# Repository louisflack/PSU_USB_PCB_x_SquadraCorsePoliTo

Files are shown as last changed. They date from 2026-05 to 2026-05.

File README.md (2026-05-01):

# PSU_USB Power Board
**Squadra Corse PoliTo — Formula Student (Season SC25)**





## 🏎️ System Overview

This repository contains the hardware design for the PSU_USB board. The primary purpose of this board is to provide a highly stable 5V power supply to electronics boards across the vehicle system. 

Utilizing a standard USB-C connector, the board is designed for maximum utility and ease of use, allowing critical racing electronics to be powered up directly from any standard power supply or PC during bench testing and debugging. 

## ✨ Key Features & Hardware Specifications

* **Connector:** USB-C Female Connector (Molex / Wurth Elektronik).
* **Power Output:** Configured to deliver a stable 5V at up to 3A (15W).
* **PD Negotiation:** To optimize board space and reduce system complexity, a dedicated Power Delivery (PD) integrated circuit was intentionally omitted. Instead, two 5.1 kOhm pull-down resistors are tied to the CC1 and CC2 pins to strictly hardware-limit the connection to standard 5V operation.
* **Operating Temperature:** Designed to withstand standard automotive/racing environments from -40°C to 85°C.
* **Form Factor:** Extremely compact footprint measuring 27.94mm x 30.10mm.

## 🧠 Subsystem Engineering & Design Highlights

### 1. Multi-Stage Protection Circuits
To protect downstream electronics from bench-power anomalies, the board features a robust 3-stage protection strategy:
* **Reverse Current Protection:** An STPS2L40AF Zener diode with a low voltage drop is placed inline to prevent back-feeding into the source.
* **ESD Protection:** An SMAJ30CA-TR TVS diode provides fast, bidirectional repelling of voltage spikes and electrostatic discharge.
* **Over-Voltage & Over-Current:** Handled via a parallel 5.6V Zener diode (D3) paired with a fast-blow inline fuse (C1Q_1).

### 2. Dual-Stage Power Filtering
Stable power is critical for sensors and MCUs. The board utilizes two filter stages to condition the USB input:
* **LPF Filter:** A Low-Pass Filter (10uF capacitor and 10kOhm resistor) debounces the physical power switch (S1) and increases output stability, achieving a 1.6Hz cutoff frequency.
* **PI Filter:** A classic PI filter network (using a BLM31KN102SH1L ferrite bead) cleans high-frequency noise from the DC line. *Design Note: While standard USB filtering calls for a bulk electrolytic capacitor, packaging constraints forced a pivot to a Multi-Layer Ceramic Capacitor (MLCC). While slightly less performant, this trade-off was necessary to meet the strict spatial requirements of the board.*

### 3. Integrated Testability
For rapid debugging, the top layer includes dedicated, labeled test points: `GND`, `5V PRE` (to verify raw USB-C output), and `5V POST` (to verify the output after the filters and protection circuits).

## 📁 Repository Structure

```text
├── Gerbers/                  # Production files for manufacturing
├── BOM/                      # Bill of Materials
├── Schematics/               # PDF exports of the circuit design
├── Step/                     # 3D Model of the board for mechanical packaging
├── PSU_USB_v1.0_Report.pdf   # System and Subsystem Specification Document
└── README.md

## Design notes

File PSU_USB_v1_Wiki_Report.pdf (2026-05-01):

Project: PSU_USB

Version: 1.0

Object: System and Subsystem Specification, System And Subsystem Design Description

Design Season: SC25

This document describes the specifics design decisions for the PSU_USB board, the object of this document is to describe functional and non-functional requirements. Each requirement must be a single testable unit.

Symbol | Meaning
PSU | Power Supply
USB | Universal Serial Bus
PD | Power Delivery
IC | Integrated Circuit
ESD | Electro Static Discharge
MLCC | Multi Layer Ceramic Capacitor

The PSU_USB board is meant as a useful device to power up boards that requires stable 5V power supply. Using a USB-C connector is capable of powering up electronics board with ease, connecting to any power supply or a PC.

# PSU_USB - v1.0 - SSS SSDD -

SC25

# Document Overview

# Acronym and Abbreviations

# System Overview

Board 3D View

Top View

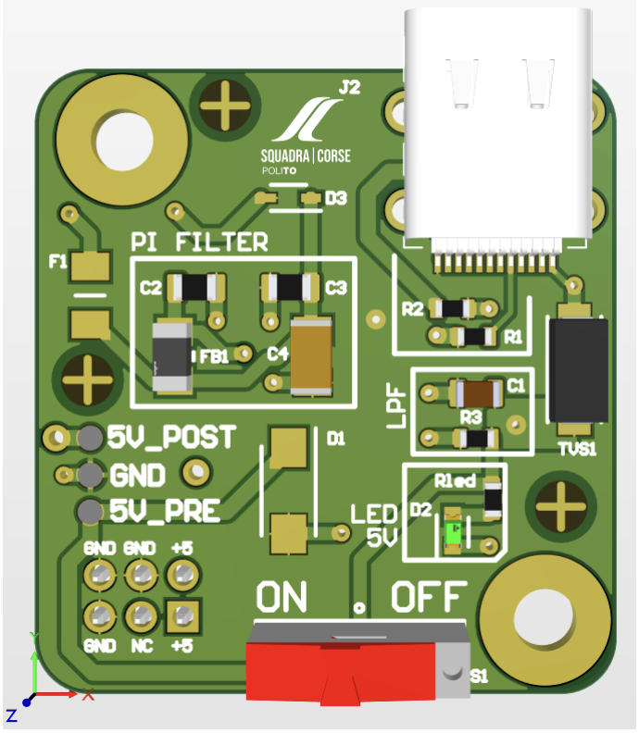
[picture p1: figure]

Bottom View (https://wiki.squadracorsepolito.com/uploads/images/gallery/2024-09/b2PyJggTqTmplOPx-screenshot-2024-09-16-alle-12-46-47.png)

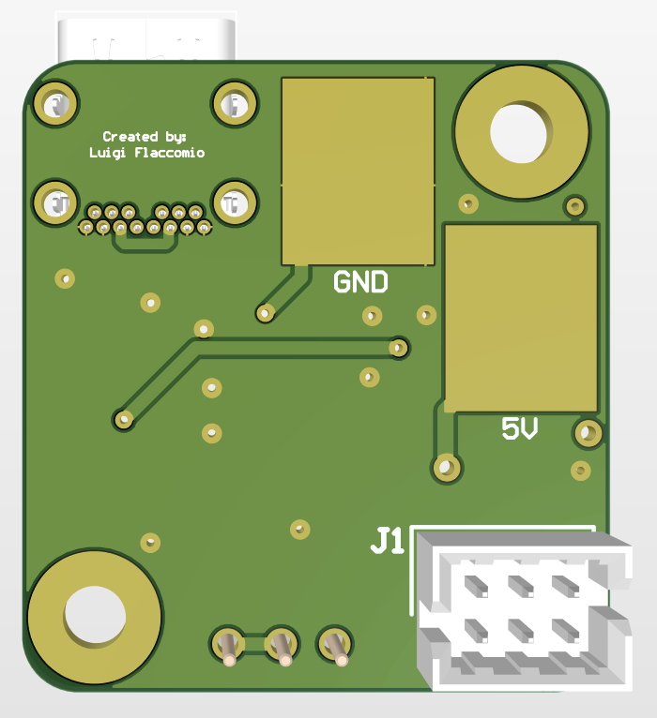
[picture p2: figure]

Reference | Name | Source | Description
632723300011 | USB-C Female Connector | Data Sheet (https://www.we-online.com/components/products/datasheet/632723300011.pdf) | Data Sheet of the USB-C female connector
SMAJ30CA-TR | TVS Diode | Data Sheet (https://www.mouser.it/datasheet/2/389/smaj10ca-2956135.pdf) | Data Sheet of the TVS Diode

# Referenced Documents

USB-C Circuit Design Rules (https://electronics.stackexchange.com/questions/649390/usb-c-port-circuit-design-esd-filtering-short-circuit-protection)

5V Connection for USB-C (https://forum.digikey.com/t/simple-way-to-use-usb-type-c-to-get-5v-at-up-to-3a-15w/7016)

Complete Guide to USB C Usage (https://www.ti.com/lit/wp/slyy109b/slyy109b.pdf?ts=1721626865685)

USB Filtering (https://andybrown.me.uk/2015/07/24/usb-filtering/)

The PSU_USB board has the only purpose to supply 5V through a USB-C connector to power up the electronics board with ease. The board has only one operating mode:

Power ON: The Led light is turned ON, the switch is in the ON position and the board is functioning properly;
Power OFF: The Led light is turned OFF, the switch is in the OFF position and the board is not giving any output;

In the following sections a deeper dive into the schematic choices has been explained. The full schematic can be viewed in the following picture:

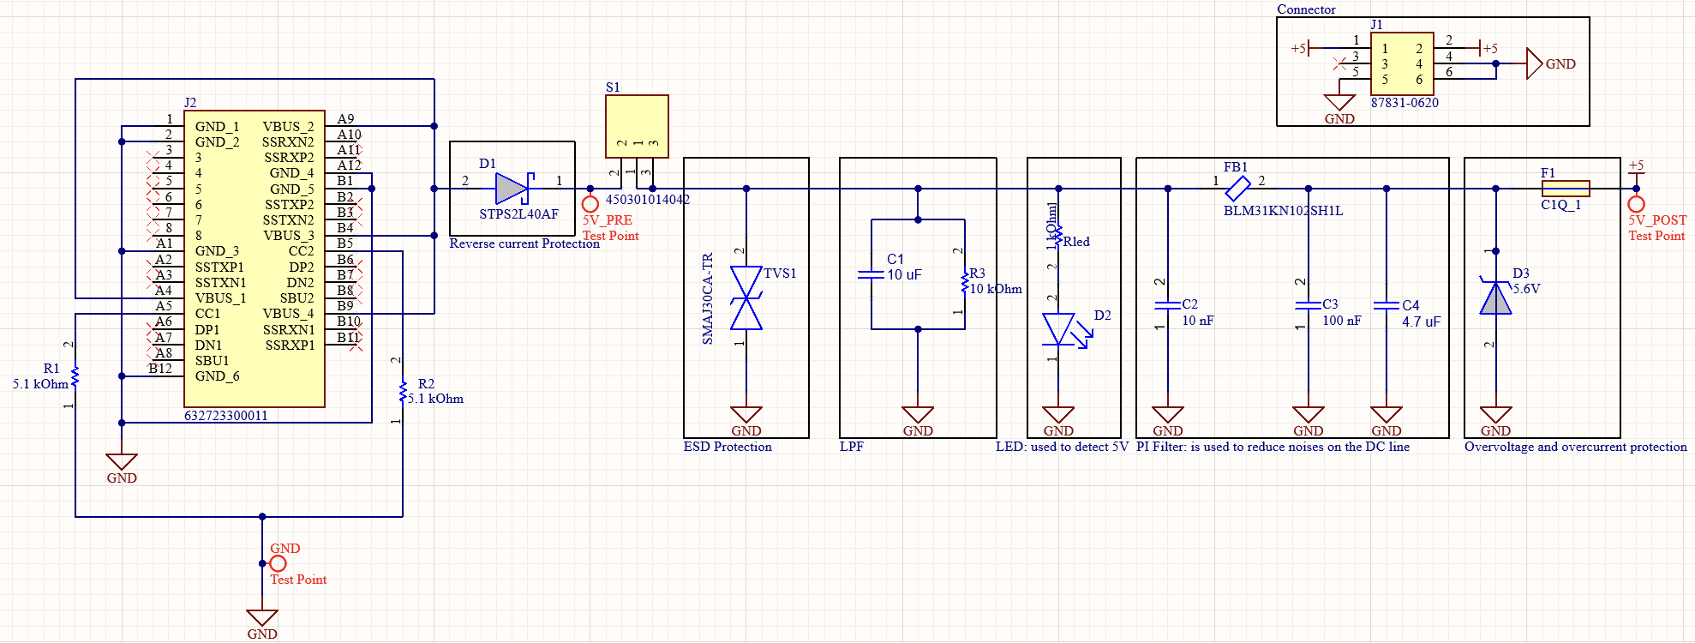
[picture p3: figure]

PSU_USB board can be connected to any power source via USB-C connector. The cable will then only supply 5V to the circuit due to USB standard limitation.

# Also viewed:

# Requirements

# Required States and modes

# Design Choices

# USB C Connection

USB-C connection

USB-C is a well known standard for data transferring and power application. A very important aspect of this connector is the possibility to use a Power Delivery mode that increases the power that can be delivered to the device. A pinout of the connector can be seen in the picture below:

Normal USB devices, without the use of a negotiation IC can only supply 5V at 3A, making up a power of only 15W. With the use of a PD Negotiation Chip, instead, is possible to increase this value by a lot, making it possible to power up a device with power that can easily arrive to 240W with the latest standard USB 3.1.

In this specific application, since only a 5V was required, it has been decided to not use a PD negotiation chip. By doing this, the complexity of the entire system was simplified and board space was optimized.

The only constraint that is required to not use a PD IC is to use 2 Pull Down Resistors connected to the CC1 and CC2 pins of the connector. By doing this, the connector is limited to 5V 3A (15
W) of maximum output. Also, for better clarity, a list of all the connections can be done:

VBUS pins: For power applications like in this case, all VBUS pins can be connected together and contribute to the power output;
CC1 and CC2 pins: To limit the voltage to 5V, two 5.1 kOhms resistors have been connected from each pin to GND reference;
GND pins: All ground pins are connected together to a ground reference;

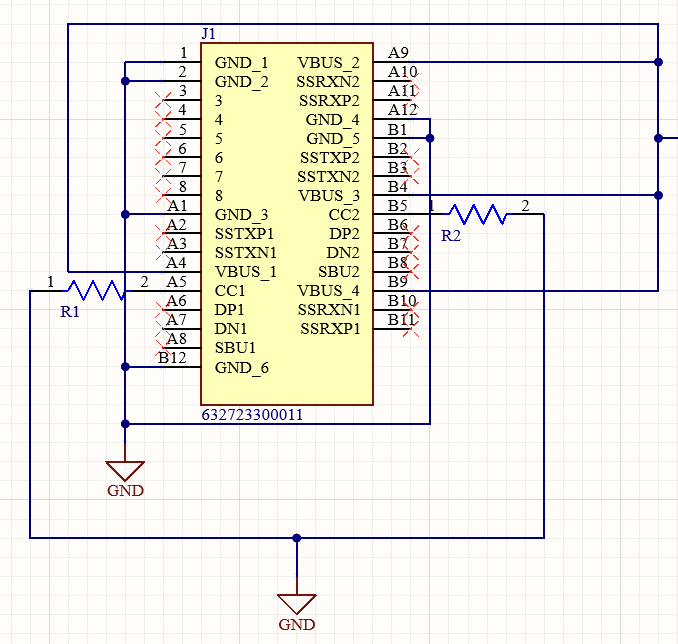
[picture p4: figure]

All other pins are left unconnected for this application;

PSU_USB has different protection circuits to avoid problems during working hours. All the circuits are described in sections below.

Protection Circuits

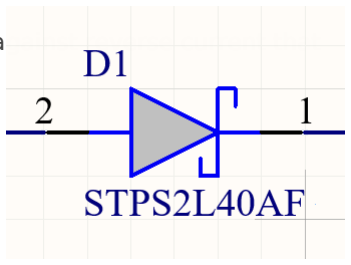
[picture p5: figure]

A Zener diode with low voltage drop is used to protect the circuit against reverse current that (https://wiki.squadracorsepolito.com/uploads/images/gallery/2024-09/KrWaDBcJLVNWTZx4-screenshot-2024-09-16-alle-14-14-58.png)

can occur when the circuit is connected to a device via USB cable.

The circuit must be protected against ESD. This can be achieved by using a TVS diode that have fast response and can repel voltages peaks from both directions.

## Reverse current protection

## ESD Protection

# Internal Protection Circuits

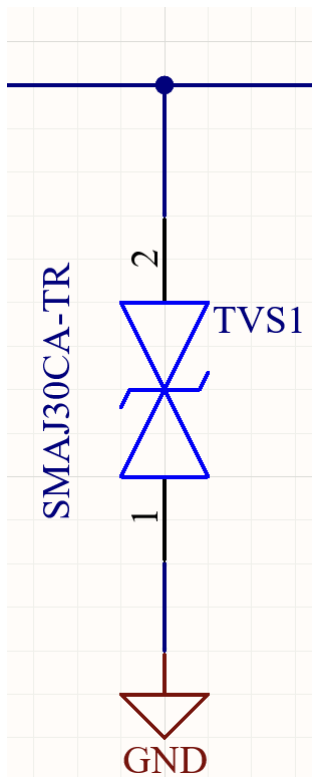
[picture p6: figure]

The most important protection circuit is against Overvoltage and overcurrent that can occur during usage. In this case a diode and a fast blow fuse do the job.

Overvoltage and (https://wiki.squadracorsepolito.com/uploads/images/gallery/2024-09/JQJcJA5ofqvYUXoV-screenshot-2024-09-16-alle-14-15-11.png) Overcurrent Protection

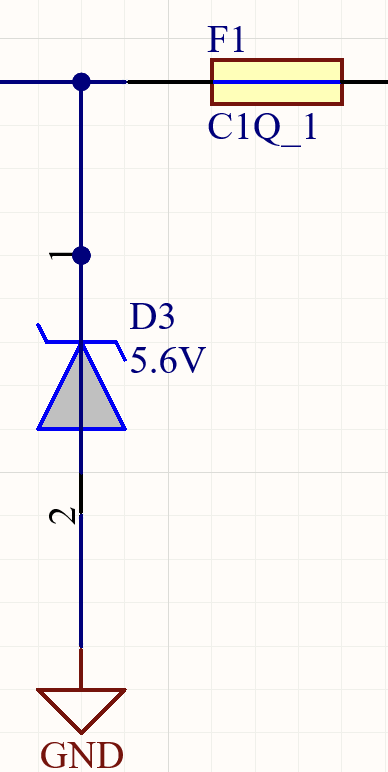
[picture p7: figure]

Filters

# Filtering Circuits

To guarantee a stable 5V supply, filters must be used. In this case 2 filters are used in the circuit.

In order to avoid bouncing due to the switch S1 used in the circuit, a LPF filter is used. In this case the filter also helps with improving the stability of the final output of the circuit, working together with the other PI filter. With the components used (C1: 10uF and R3: 10kOhm) a 1.6Hz cutoff frequency can be realized, with a time constant of about 100 ms.

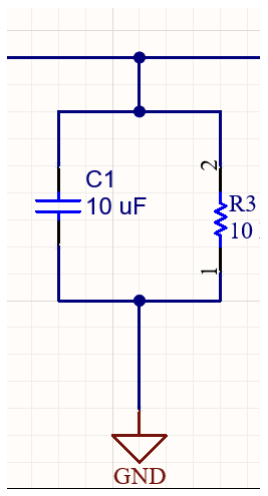
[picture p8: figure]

The PI Filter is a very common configuration used in power application to guarantee a stable output. In this case, since the USB-C connector could be connected to any power source (PC or other power supply), a very important role is played by this filter in avoiding noise in the output voltage. The values chosen in this case have been taken from an existing configuration specifically used in USB application, with some differences:

C4, in the original configuration, should be an Electrolytic capacitor with low ESR. This because it serves as a bulk where the noise can go to avoid disturbances in the circuit. After some considerations, since an electrolytic capacitor would have been too big, a MLCC with low ESR and much less impact in terms of occupied space has been chosen. This capacitor makes the circuit work worse, but the trade offs between space occupation and performance have been better satisfied.
C2 and C3 have been left unchanged from the original configuration since the working principle was fulfilled.

A comparison between the original configuration and the one chosen can be observed below:

Original Configuration | Chosen Configuration

## LPF Filter

## PI Filter

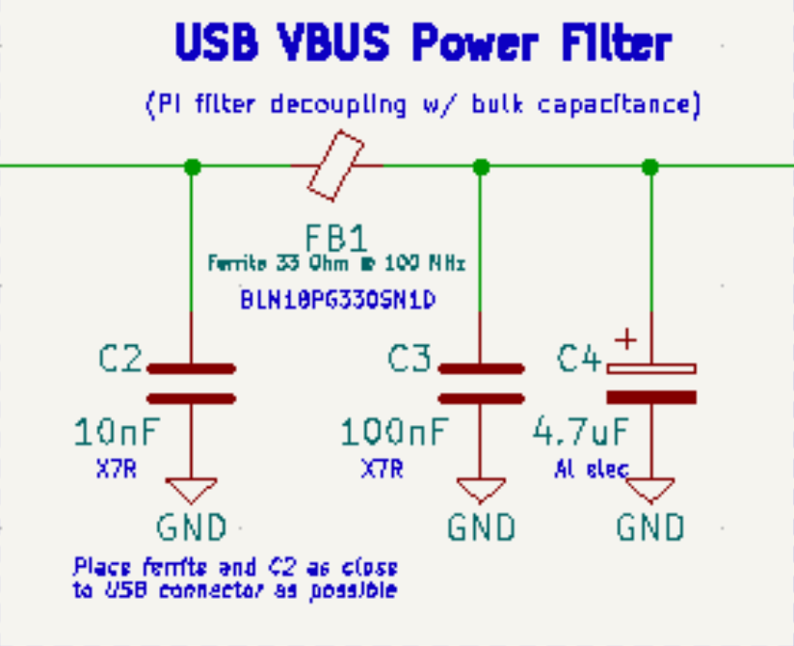
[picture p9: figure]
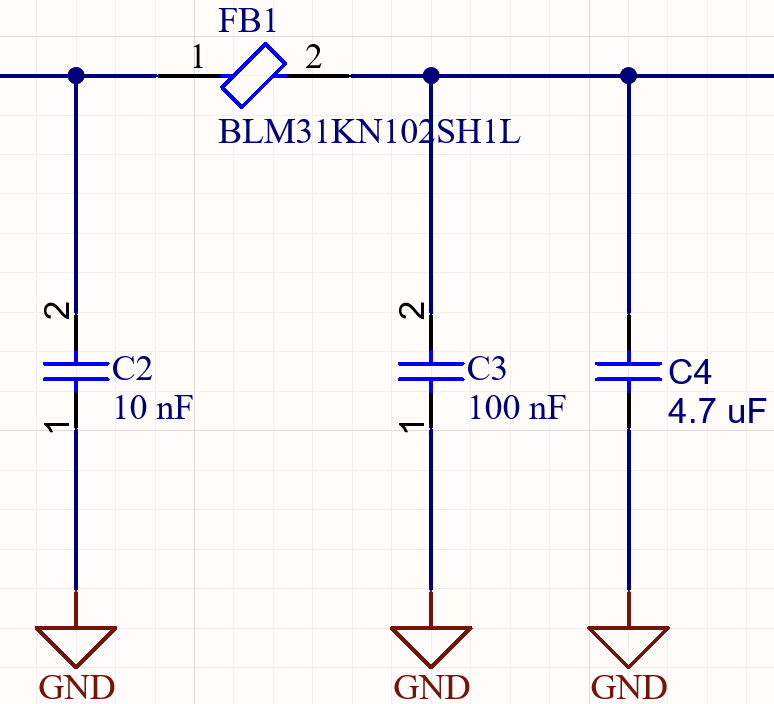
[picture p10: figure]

In order to correctly test the functions of the PSU_USB board, some steps can be followed. It is important to notice that 3 different testing points (GND, 5V PRE, 5V POST) are present on the top layer of the board, allowing for easier testing procedures.

To test the board a multimeter is needed. In this case, the multimeter has to be set in voltage measurement configuration.

The testing procedure has to be performed like it follows:

The negative multimeter lead has to be maintained fixed to the GND testing point on the board;
The positive multimeter lead has to be moved between the 2 remaining points (5V PRE & 5V POST);
To test the correct 5V output of the USB-C connector, the positive lead has to be put onto the 5V PRE testing point;
To test the correct functioning of the filters and protection circuit, the positive lead has to be put onto the 5V POST testing point;

# Testing Procedures

# Testing instruments

# Testing steps

# Expected results

In order for the board to work properly, the result of each measurement done on the 5V PRE and the 5V POST testing points has to be the same: 5 Volts of stable DC Voltage should be read on the multimeter screen.

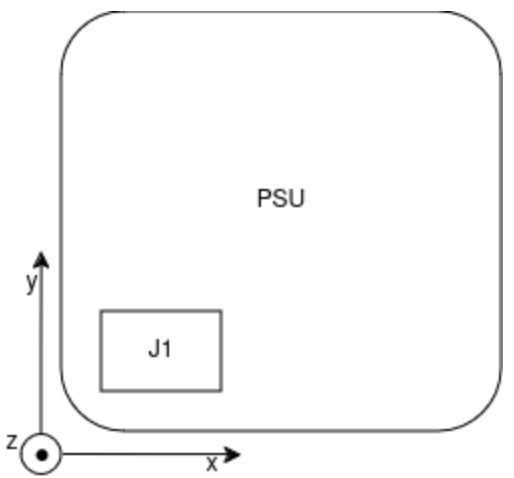
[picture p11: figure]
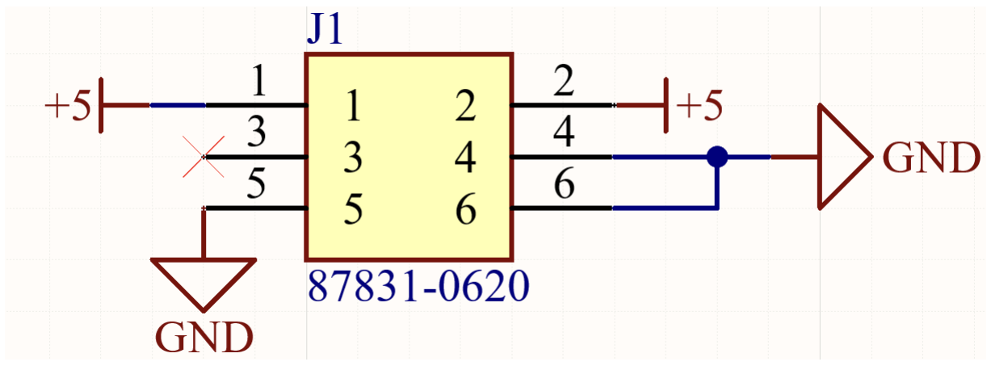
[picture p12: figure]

Device Side (J1):
Molex 2x3 straight milligrid Male Connector, PN: 87831-0620

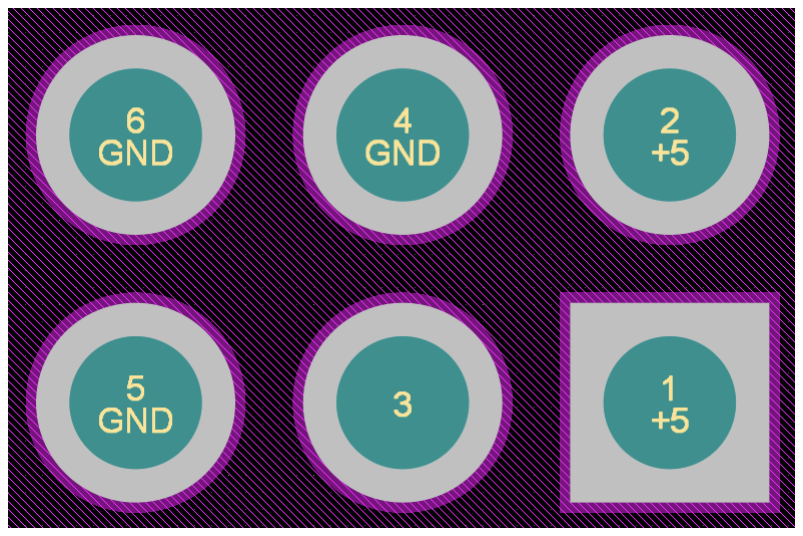
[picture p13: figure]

Connector that attaches to PSU on the PCB:
Molex 2x3 straight milligrid Female Connector, P/N: 79107-7002
PIN # | Signal Name | Function | Type
1 | +5 | 5 Volts from the USB-C Connector | OUT

# System External Interface Requirements

# Interface Identification and Diagrams

# J1 - Connector

PIN # | Signal Name | Function | Type
2 | +5 | 5 Volts from the USB-C Connector | OUT
3 | / | Not Used | /
4 | GND | Ground Reference | IN/OUT
5 | GND | Ground Reference | IN/OUT
6 | GND | Ground Reference | IN/OUT

The temperature of the PSU_USB board has to be in the range between -40°C to 85°C.

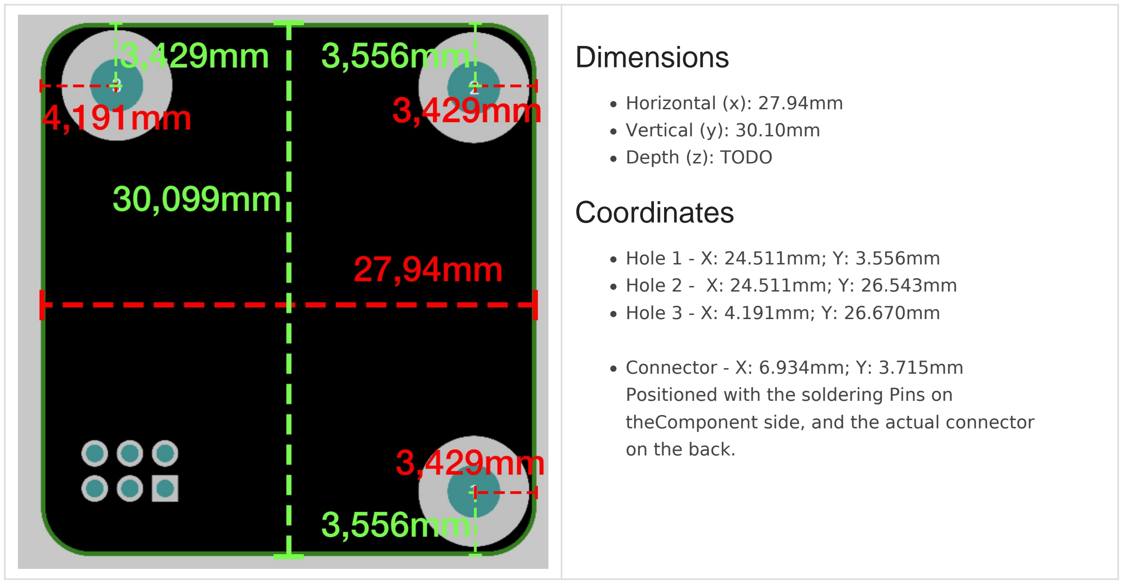
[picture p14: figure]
Horizontal (x): 27.94mm Vertical (y): 30.10mm Depth (z): TODO; Hole 1 - X: 24.511mm; Y: 3.556mm Hole 2 - X: 24.511mm; Y: 26.543mm Hole 3 - X: 4.191mm; Y: 26.670mm; Connector - X: 6.934mm; Y: 3.715mm Positioned with the soldering Pins on; on the back.; Dimensions; Coordinates

theComponent side, and the actual connector

# System Environment Requirements

# Design And Construction Constraints

# Dimension Requirements

Revision #11
Created 16 September 2024 10:35:55 by Luigi Updated 20 July 2025 19:41:20 by Luigi

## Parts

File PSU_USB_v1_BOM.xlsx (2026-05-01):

Comment | Description | Designator | Footprint | Quantity
Test Point | Test Point | 5V_POST, 5V_PRE, GND | TestPoint_FP | 3
10 uF | GRM21BR71A106KA73K | C1 | CAPC0805(2012)145_L | 1
10 nF | CC0805MRX7R9BB103 | C2 | 0805_General | 1
100 nF | CL21B104MACNNNC | C3 | 0805_General | 1
4.7 uF | VJ1206G475MXQTW1BC | C4 | CAPC3216X190X55LL30T25 | 1
Schottky Diodes & Rectifiers 40V Low Drop Rec 2A If 0.34V VF | STPS2L40AF | D1 | SODFL5226X110N | 1
3.8 V | VLMB1300-GS08 | D2 | FP-6_541-5092_01-4-MFG | 1
5.6V | DDZ5V6ASF-7 | D3 | SODFL2512X75N | 1
C1Q_1 | Fuse 500 mA | F1 | FUSC3216X78N | 1
Chip Ferrite Bead, 1206, 1000Ω @ 100MHz, 0.075Ω, 25%, 2A | BLM31KN102SH1L | FB1 | FP-BLM31-0_2-t1_6-IPC_C | 1
Fiducial |  | FID1, FID2, FID3 | Fiducial-Footprint-1 | 3
Header 2.00mm Milli-Grid | 87831-0620 | J1 | SHDR6W55P200_2X3_865X630X640P | 1
Type C USB 3.2 Gen 2 Connector | USB4230-03-A_REVA | J2 | GCT_USB4230-03-A_REVA | 1
MH_M3_with_pin | Mounting hole m3 | MH1, MH2 | MH_M3-Footprint-1 | 2
5.1 kOhm | CRCW06035K10FKEA | R1, R2 | 0603_General | 2
10 kOhm | rcs060310k0fkea | R3 | 0603_General | 1
1 kOhm | CRCW06031K00FKEAHP | Rled | RESC0603(1608)_L | 1
Mini Slide Switch 10x2.5mm SPDT on / on Through Hole Slide Switch SPDT On-On 100 mA@ 42 V dc Slide | 450301014042 | S1 | 450301014042 | 1
TVS Diode Bi-Directional SMAJ30CA-TR 64.3V | SMAJ30CA-TR | TVS1 | DIONM5126X265N | 1

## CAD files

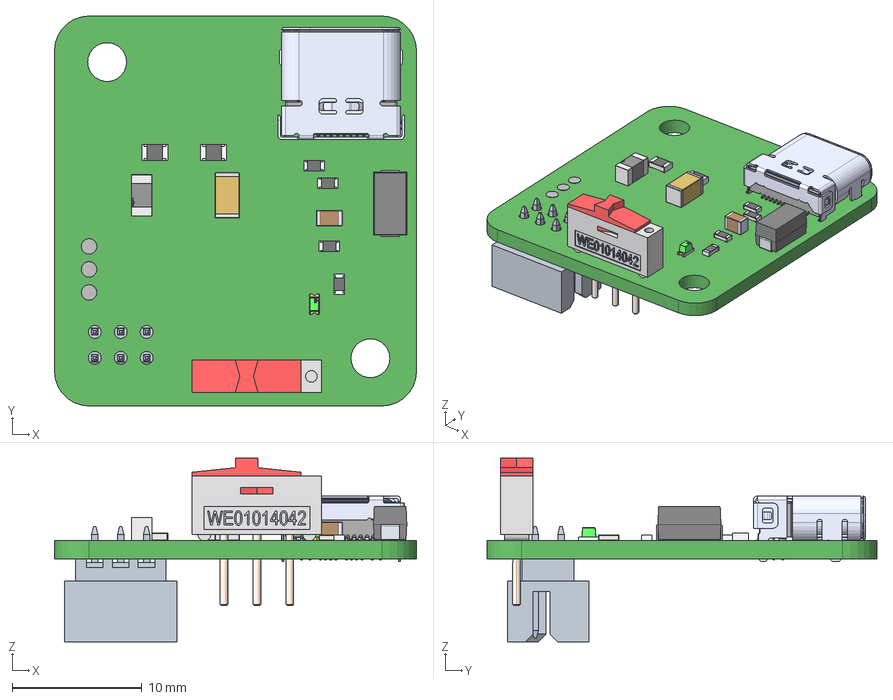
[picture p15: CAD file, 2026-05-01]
PSU_USB_v1.step
27.9 x 30.1 x 14.2 mm
RES0603 x 4
FilletPin1
FilletPin2
Terminals
Center
Murata
terminals
base
lens
marking
RES0805 x 2
CAPC2012X145N EIA 0805
USB4230-03-A_PART1
USB4230-03-A_PART2
USB4230-03-A_PART3

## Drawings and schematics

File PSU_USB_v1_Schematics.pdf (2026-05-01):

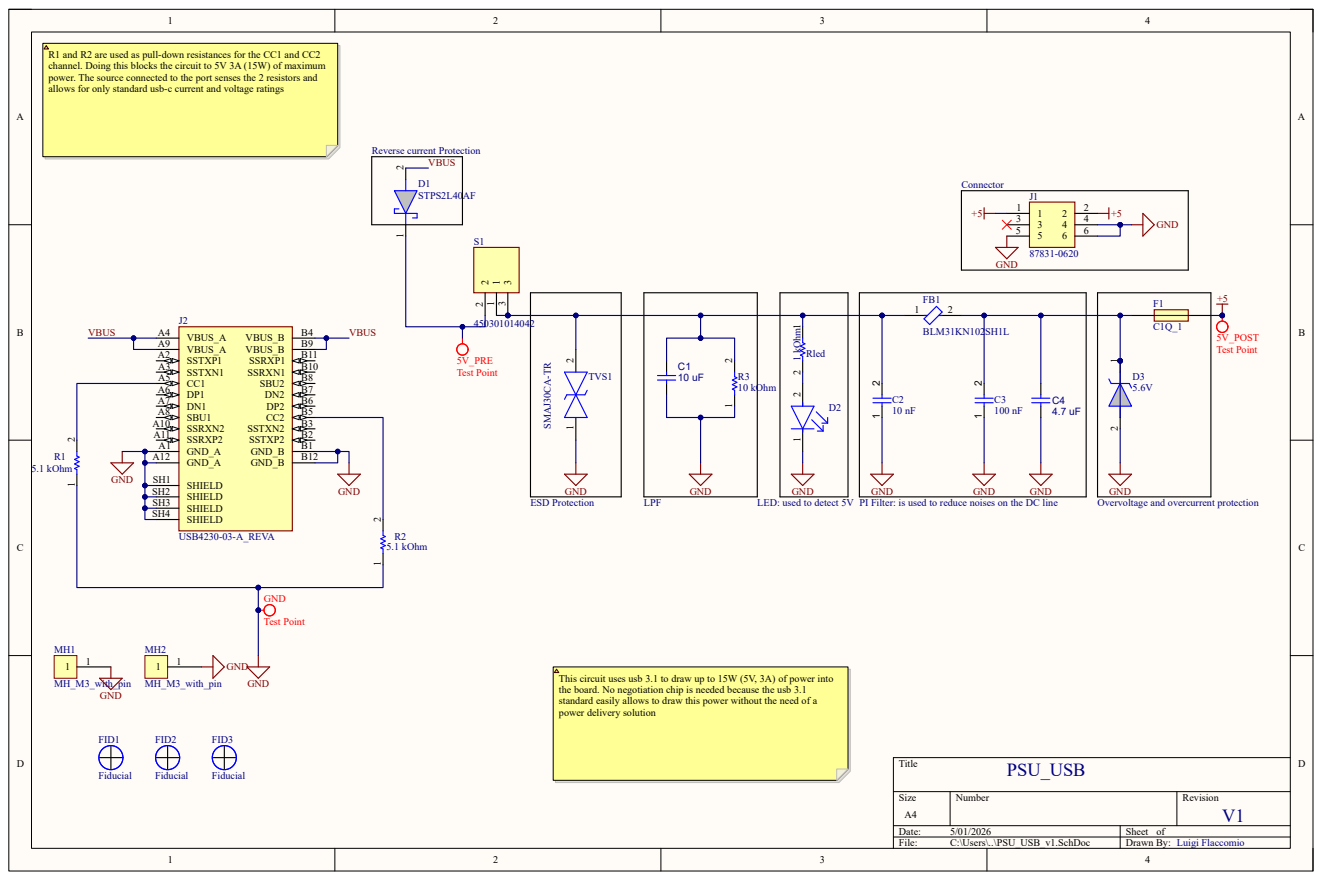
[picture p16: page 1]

R1 and R2 are used as pull-down resistances for the CC1 and CC2
channel. Doing this blocks the circuit to 5V 3A (15W) of maximum
power. The source connected to the port senses the 2 resistors and
allows for only standard usb-c current and voltage ratings

This circuit uses usb 3.1 to draw up to 15W (5V, 3A) of power into
the board. No negotiation chip is needed because the usb 3.1
standard easily allows to draw this power without the need of a
power delivery solution
